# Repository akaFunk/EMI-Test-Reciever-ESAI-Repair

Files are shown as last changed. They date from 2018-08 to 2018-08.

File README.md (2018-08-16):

# Adapters for capacitor replacemnt in an Rohde & Schwarz EMI Test Receiver ESAI
We got an old Rohde & Schwarz EMI Test Receiver ESAI which needed a little repair. The device did not boot when turning it on. Just a few LEDs switched on and nothing more happend. It turned out that two capacitors were shorting one of the power rails. Additionally the responsible fuse was blown. We decided to replace all capacitors to be on the safe side. The file ReplacementCaps.ods gives an overview of the capacitors in the two devices and the possible replacement parts. For the values 4700, 10000 and 2200 µF we were able to find fitting replacements. For the capacitors with the values 15000 and 470 µF we had to use replacements with different footprints. Two PCBs were designed to adapt the two different footprints to the original ones.

## Images
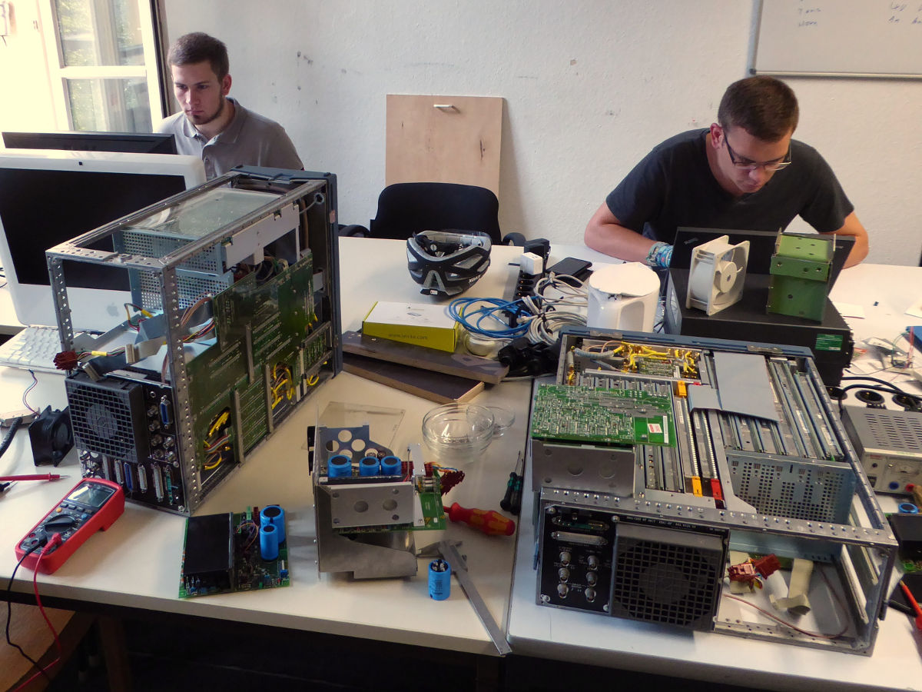
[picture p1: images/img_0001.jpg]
Working on the EMI Test Receiver

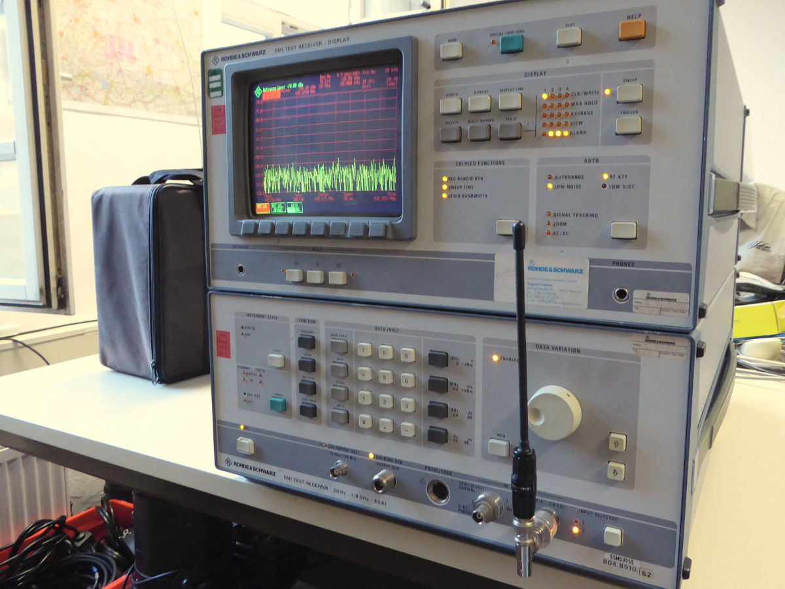
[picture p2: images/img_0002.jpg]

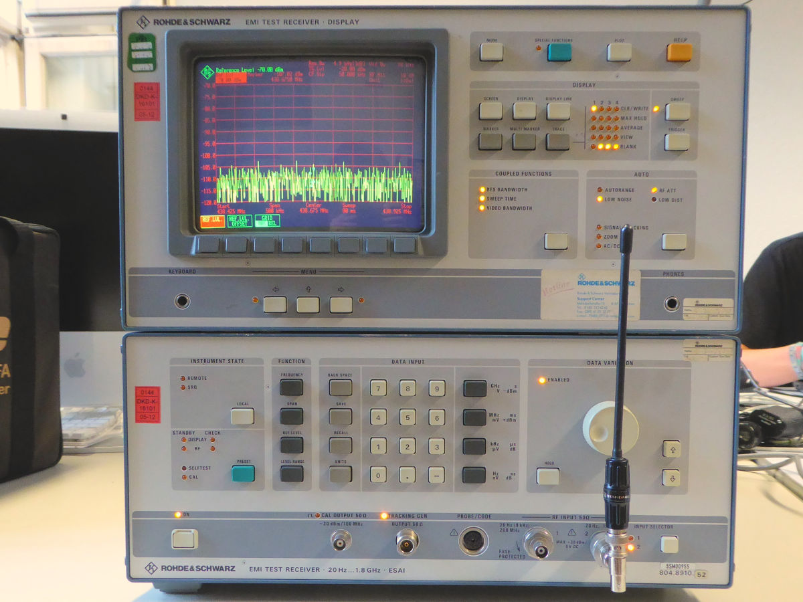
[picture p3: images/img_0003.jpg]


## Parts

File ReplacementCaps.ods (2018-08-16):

Count | Capacity | Voltage | Size | Original | Replacement | Size | Price | Comment
2 | 4700 µF | 40 V | 25x48 | 2222 051 57472 | MAL205157472E3 | 25x45 | 9,38 € | Excact fit
 |  |  |  |  | 80USC4700MEFCSN25X45 | 25x47 | 3,38 € | Alternative
3 | 10000 µF | 40 V | 35x49 | 2222 051 57103 | MAL205157103E3 | 35x45 | 10,47 € | Excact fit
 |  |  |  |  | LLS1J103MELC | 35x42 | 5,10 € | Alternative
4 | 15000 µF | 16 V | 30x49 | 2222 051 55153 | LGU1V153MELB | 30x47 | 3,54 € | Alternative
1 | 470 µF | 200 V | 35x49 | 2222 053 52471 | LGU2G561MELC | 35x45 | 5,69 € | Alternative
1 | 2200 µF | 63 V | 24x39 | 2222 051 58222 | MAL205158222E3 | 25x30 | 7,00 € | Excact fit
 |  |  |  |  | LLS1K222MELZ | 22x37 | 2,73 € | Alternative

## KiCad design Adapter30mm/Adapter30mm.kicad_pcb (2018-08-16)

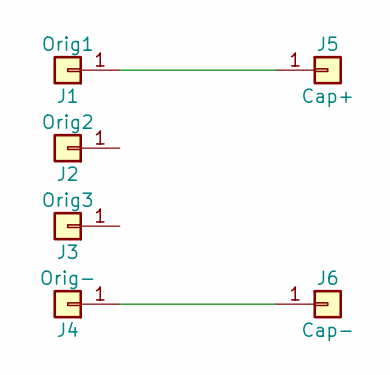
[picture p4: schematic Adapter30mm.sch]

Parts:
J1: Orig1; Hole_1.3mm
J2: Orig2; Hole_1.3mm
J3: Orig3; Hole_1.3mm
J4: Orig-; Hole_1.3mm
J5: Cap+; Hole_1.7mm
J6: Cap-; Hole_1.7mm

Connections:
unnamed: J1.1, J5.1
unnamed: J4.1, J6.1

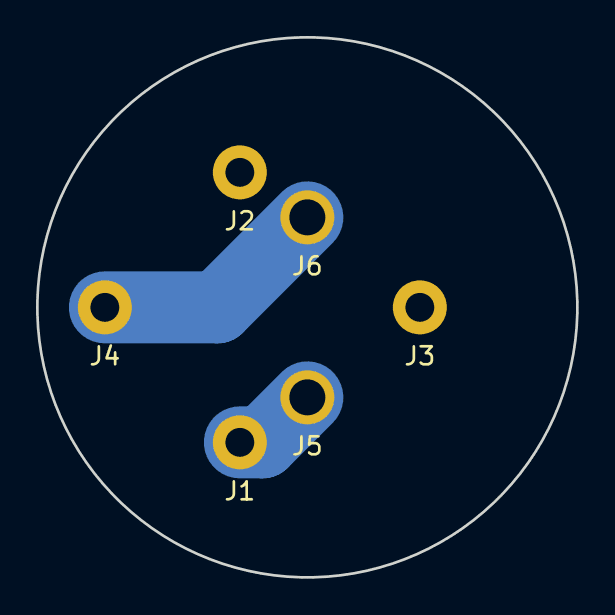
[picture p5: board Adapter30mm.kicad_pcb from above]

Board: 2 copper layers, 30.0 x 30.0 mm, 6 parts (0 on the bottom side), 2 nets.
